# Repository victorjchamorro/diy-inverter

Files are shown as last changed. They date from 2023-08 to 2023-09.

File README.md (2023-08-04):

# diy-inverter
Creación de un inversor partiendo de un Xantrex ProWatt 1400i averiado

Serie de vídeos en youtube:
[youtube](https://www.youtube.com/playlist?list=PLBt3mBwJQwRWf2Qoqq8KDot9ghxqB0hle)

Imágenes:

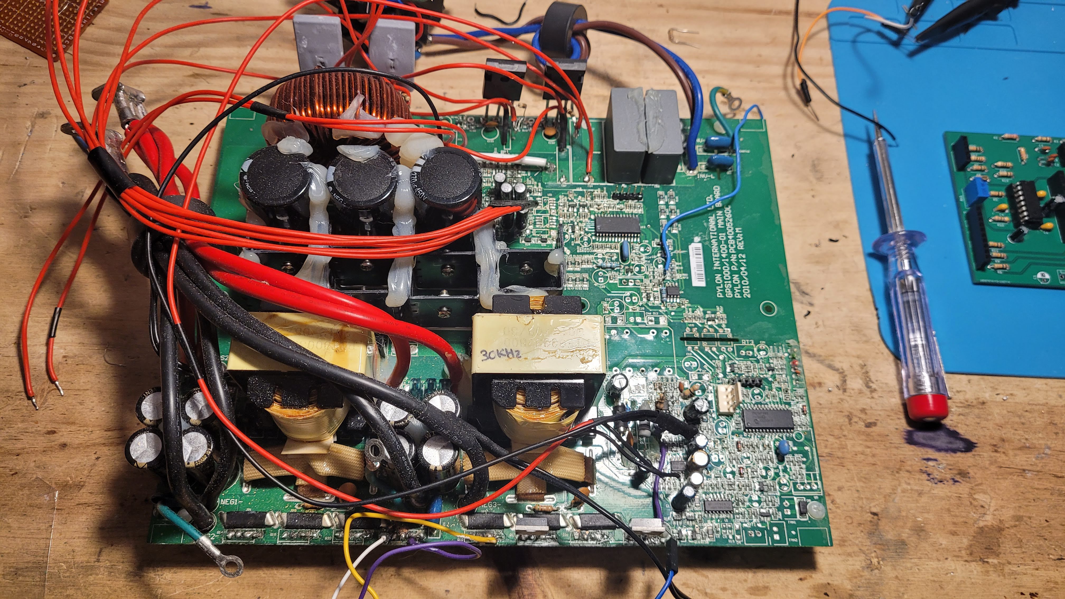
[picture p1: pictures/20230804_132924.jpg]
PCB Xantrex

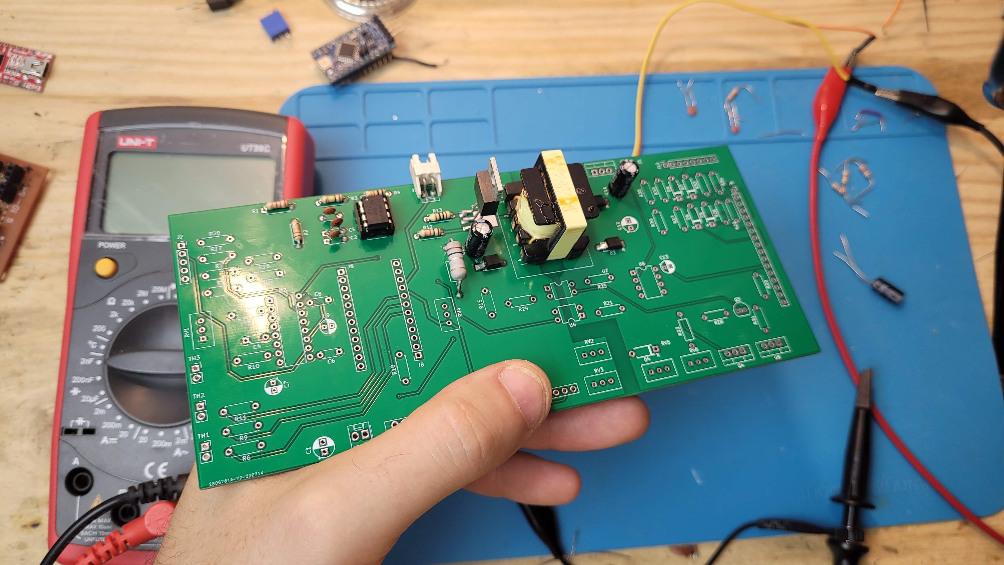
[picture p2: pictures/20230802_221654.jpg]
PCB DYI


La idea es remplazar toda la electrónica de control por un circuito nuevo, aprovechando los componentes de potencia existentes en la placa

- arduino: arduino code
- kicad: schemas and gerbers
- pictures: fotografías
- utl: utilidades

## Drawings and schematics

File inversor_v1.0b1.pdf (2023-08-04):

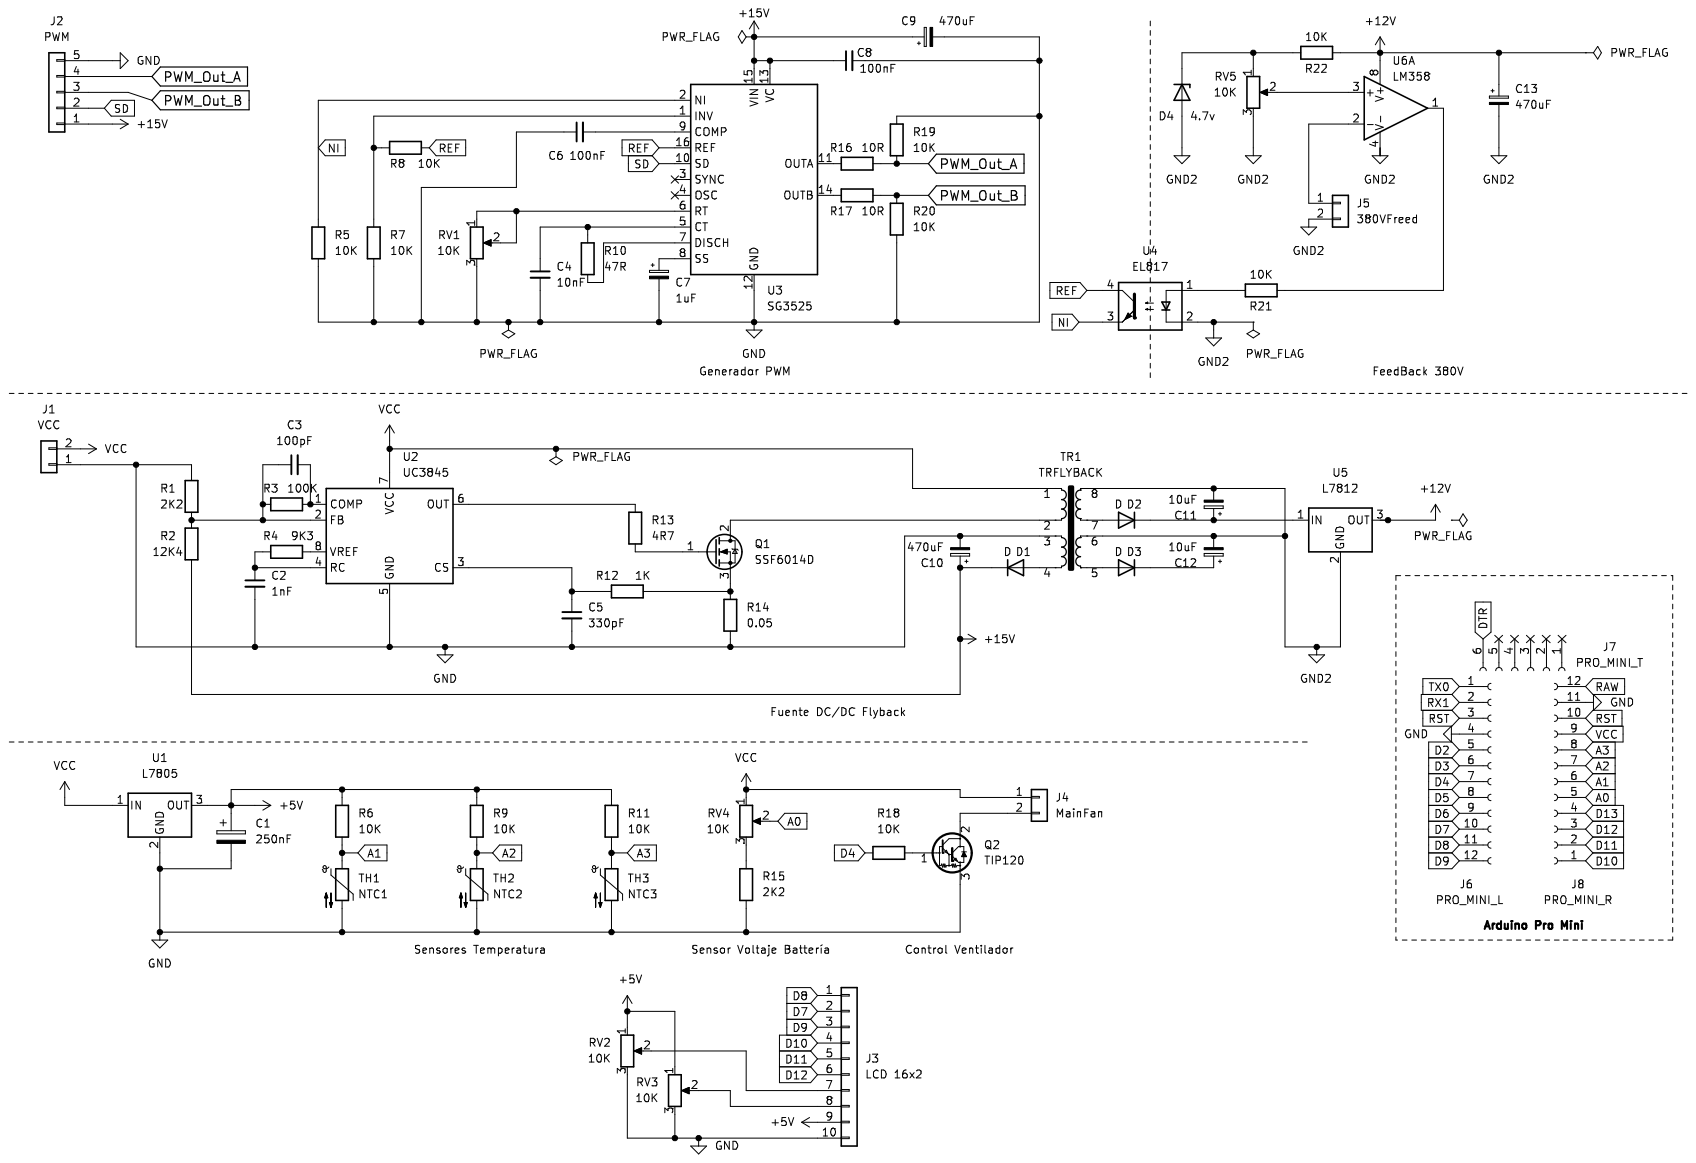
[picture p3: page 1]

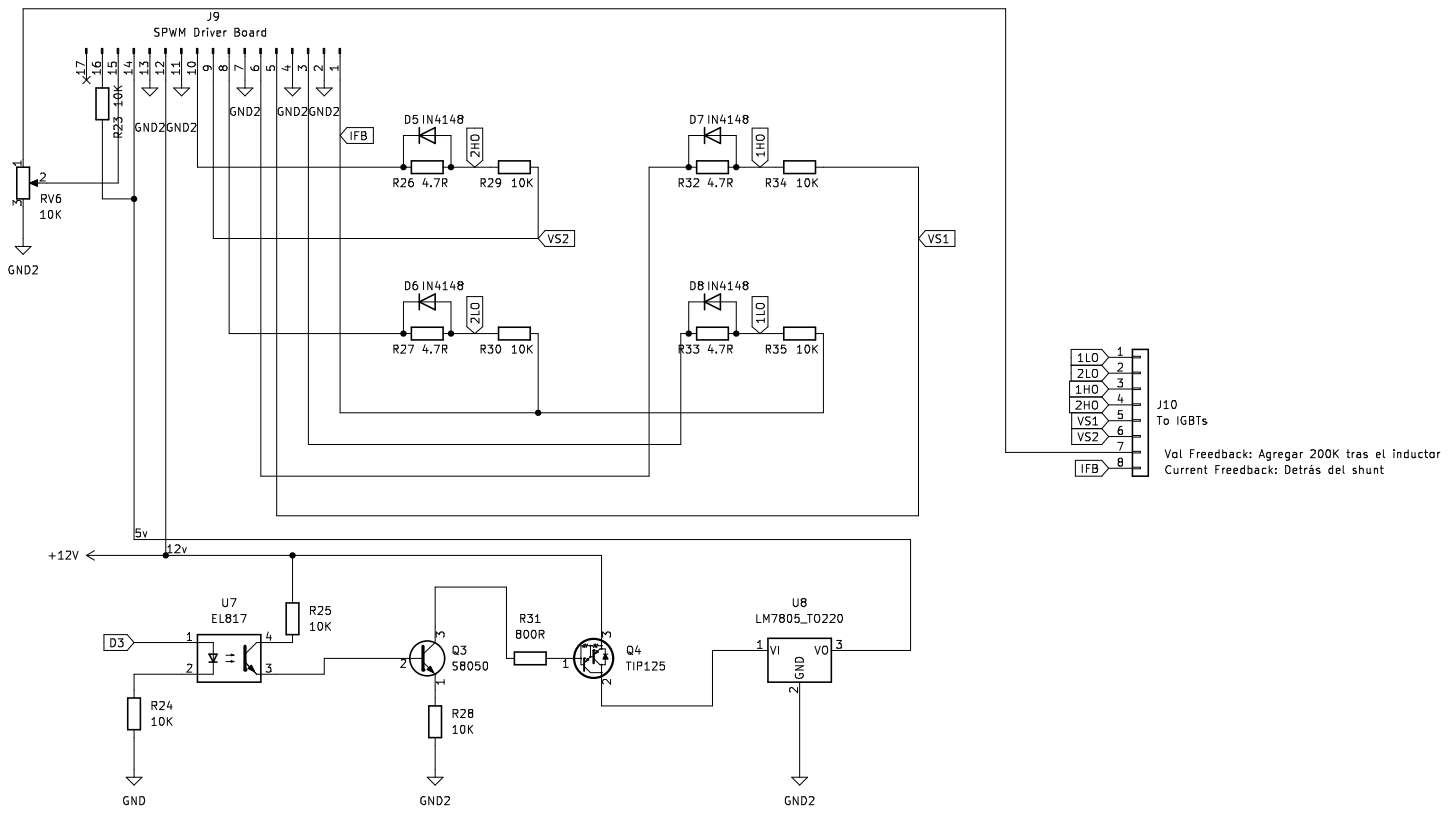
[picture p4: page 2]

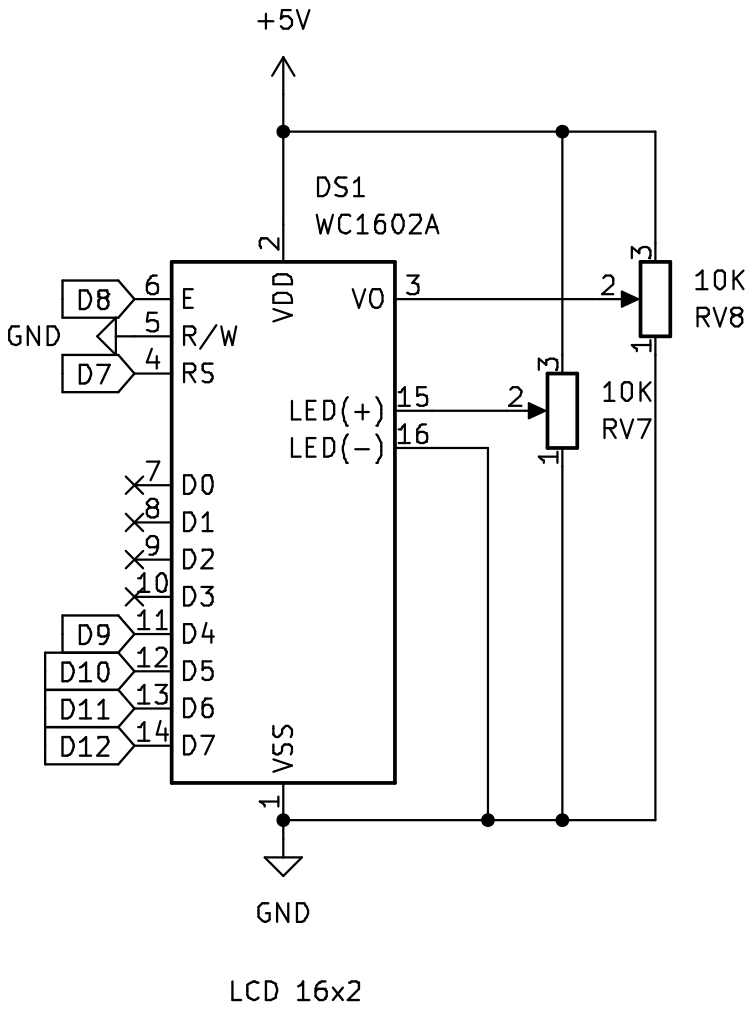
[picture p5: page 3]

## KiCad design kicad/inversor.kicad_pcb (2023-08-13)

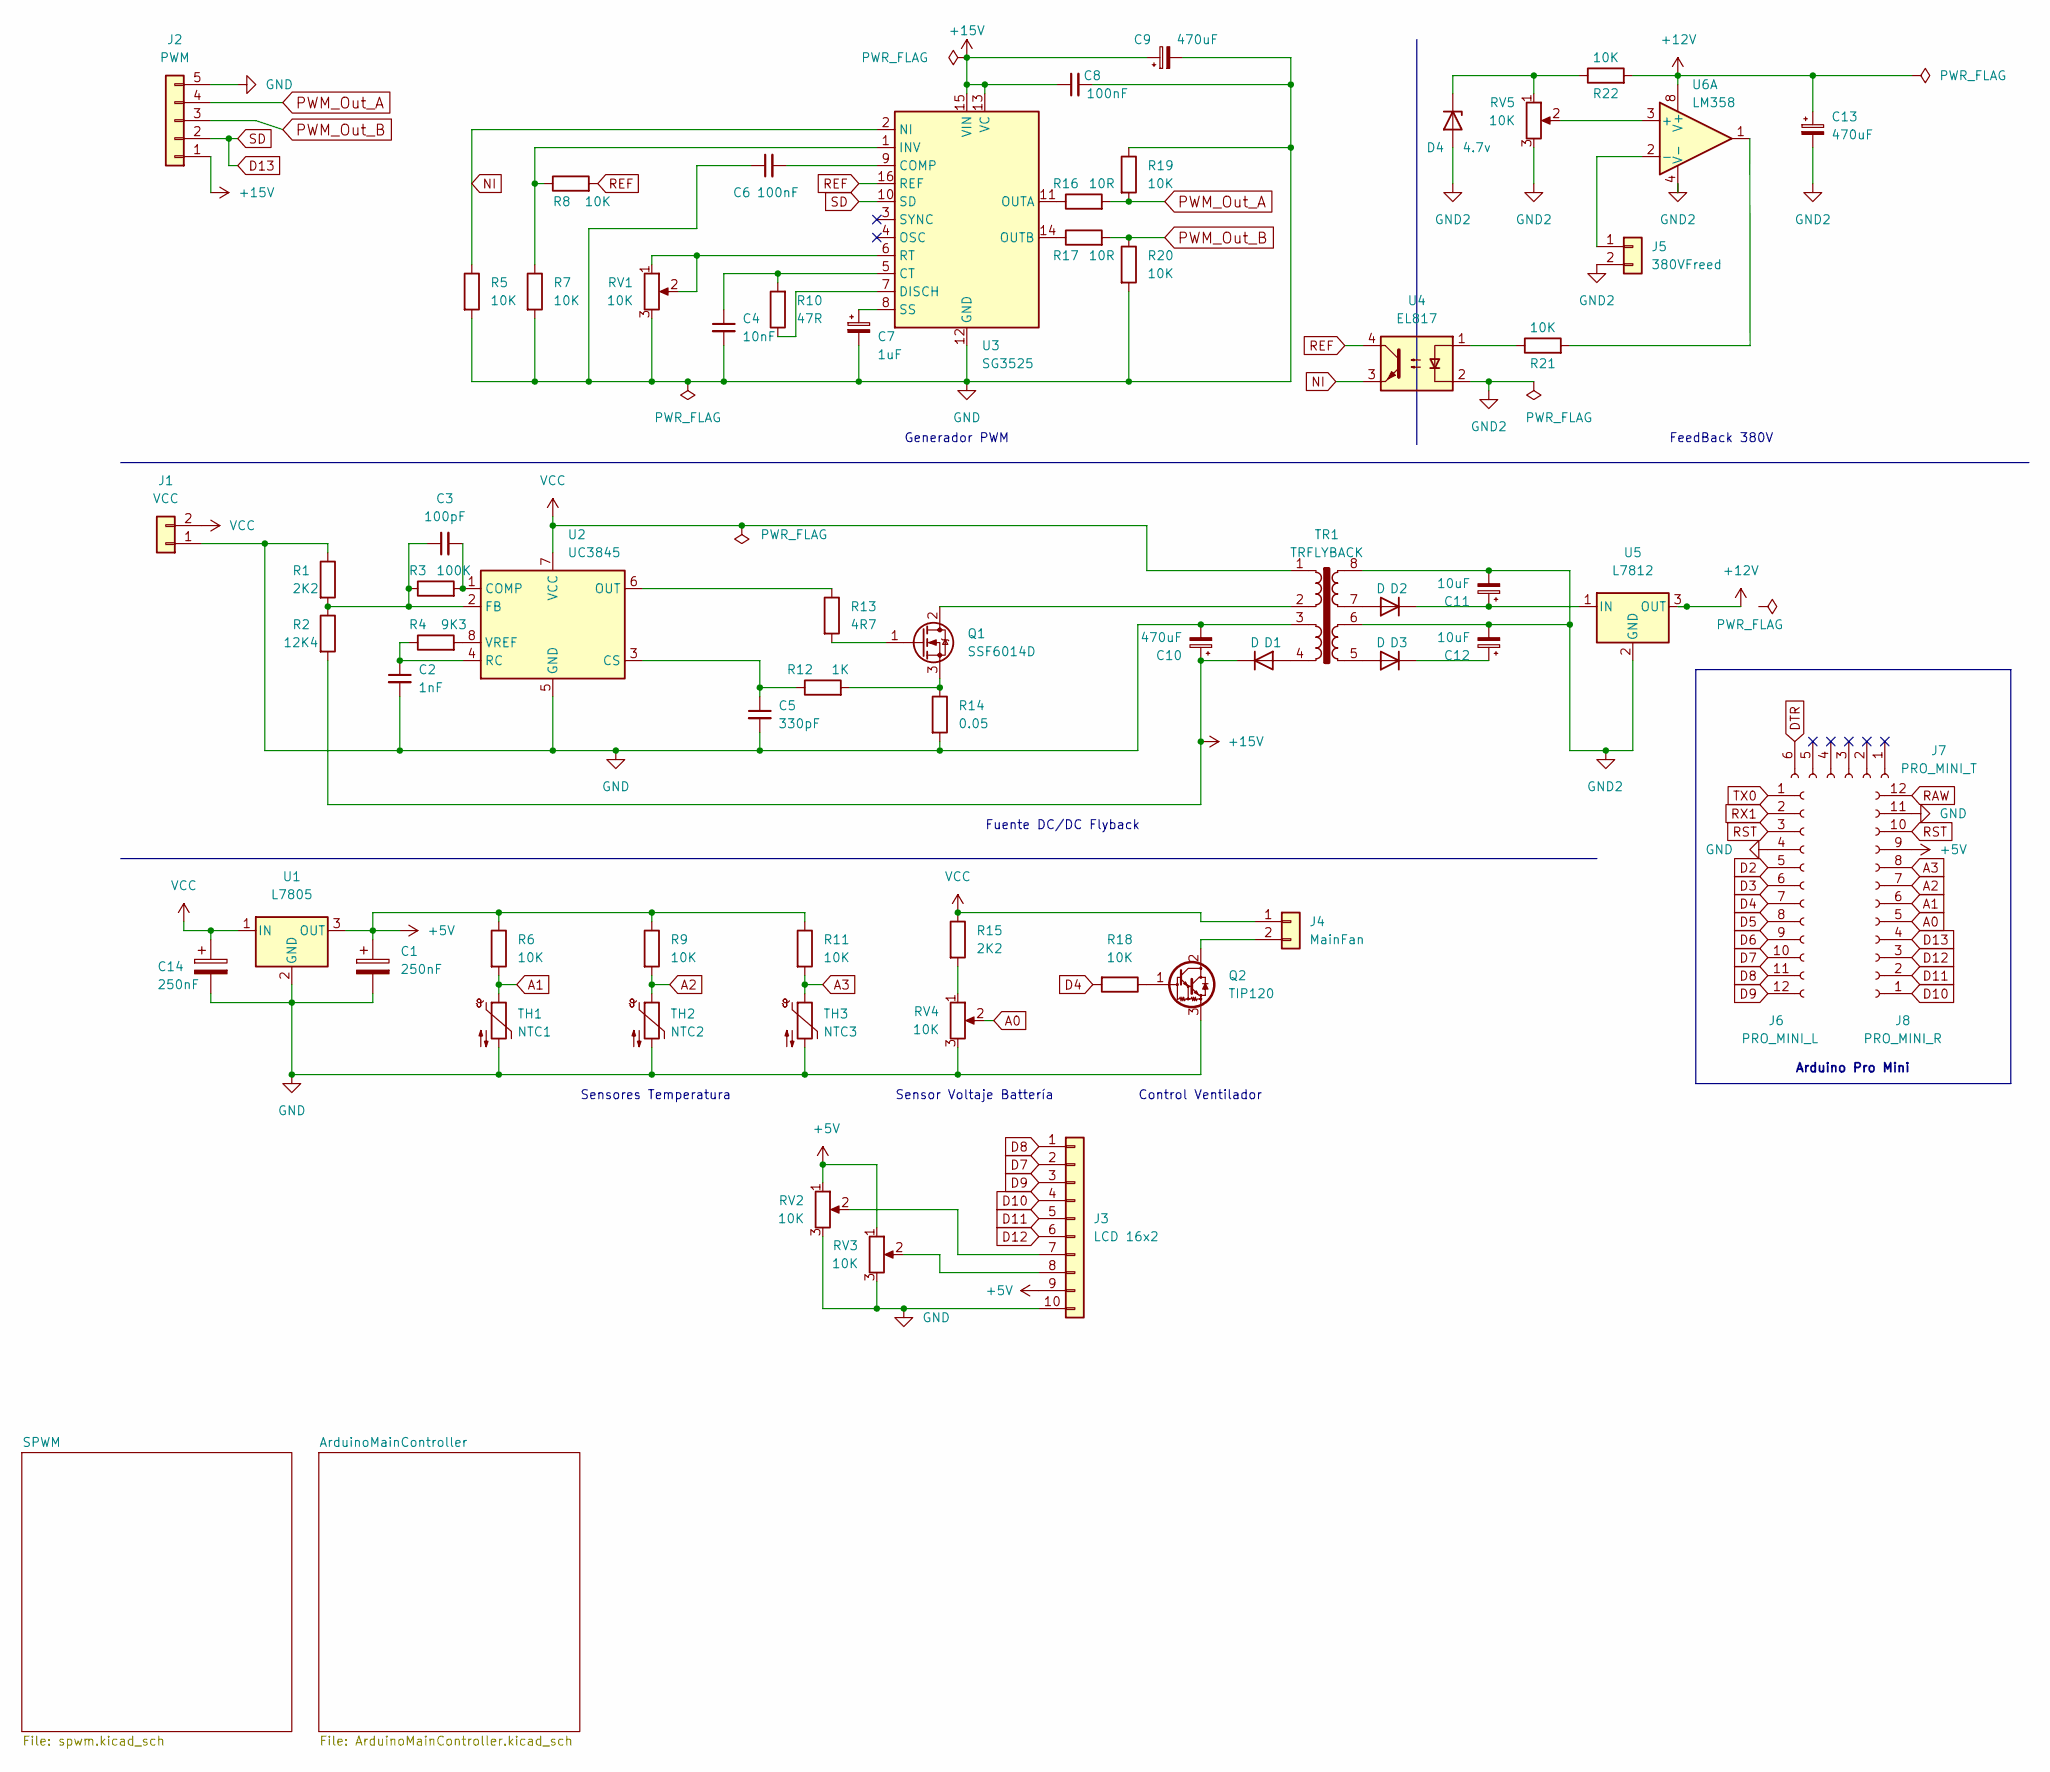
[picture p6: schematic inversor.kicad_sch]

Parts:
C1, C14: 250nF; CP_Radial_D5.0mm_P2.50mm
C2: 1nF; C_Disc_D4.3mm_W1.9mm_P5.00mm
C3: 100pF; C_Disc_D4.3mm_W1.9mm_P5.00mm
C4: 10nF; C_Disc_D4.3mm_W1.9mm_P5.00mm
C5: 330pF; C_Disc_D4.3mm_W1.9mm_P5.00mm
C6, C8: 100nF; C_Disc_D4.3mm_W1.9mm_P5.00mm
C7: 1uF; CP_Radial_D4.0mm_P2.00mm
C9, C10, C13: 470uF; CP_Radial_D4.0mm_P2.00mm
C11, C12: 10uF; CP_Radial_D5.0mm_P2.50mm
D1, D2, D3: D; D_A-405_P7.62mm_Horizontal
D4: 4.7v; D_A-405_P7.62mm_Horizontal
J1: VCC; Molex_KK-254_AE-6410-02A_1x02_P2.54mm_Vertical
J2: PWM; PinSocket_1x05_P2.54mm_Vertical
J3: LCD 16x2; PinSocket_1x10_P2.54mm_Vertical
J4: MainFan; Molex_KK-254_AE-6410-02A_1x02_P2.54mm_Vertical
J5: 380VFreed; PinSocket_1x02_P2.54mm_Vertical
J6: PRO_MINI_L; PinSocket_1x12_P2.54mm_Vertical
J7: PRO_MINI_T; PinSocket_1x06_P2.54mm_Vertical
J8: PRO_MINI_R; PinSocket_1x12_P2.54mm_Vertical
Q1: SSF6014D; TO-252-3_TabPin2
Q2: TIP120; TO-220-3_Vertical
R1, R15: 2K2; R_Axial_DIN0207_L6.3mm_D2.5mm_P7.62mm_Horizontal
R2: 12K4; R_Axial_DIN0207_L6.3mm_D2.5mm_P7.62mm_Horizontal
R3: 100K; R_Axial_DIN0207_L6.3mm_D2.5mm_P7.62mm_Horizontal
R4: 9K3; R_Axial_DIN0207_L6.3mm_D2.5mm_P7.62mm_Horizontal
R5, R6, R7, R8, R9, R11, R18, R19, R20, R21, R22: 10K; R_Axial_DIN0207_L6.3mm_D2.5mm_P7.62mm_Horizontal
R10: 47R; R_Axial_DIN0207_L6.3mm_D2.5mm_P7.62mm_Horizontal
R12: 1K; R_Axial_DIN0207_L6.3mm_D2.5mm_P7.62mm_Horizontal
R13: 4R7; R_Axial_DIN0207_L6.3mm_D2.5mm_P7.62mm_Horizontal
R14: 0.05; R_Axial_DIN0207_L6.3mm_D2.5mm_P15.24mm_Horizontal
R16, R17: 10R; R_Axial_DIN0207_L6.3mm_D2.5mm_P7.62mm_Horizontal
RV1, RV2, RV3, RV4, RV5: 10K; Potentiometer_Bourns_3296W_Vertical
TH1: NTC1; PinSocket_1x02_P2.54mm_Vertical
TH2: NTC2; PinSocket_1x02_P2.54mm_Vertical
TH3: NTC3; PinSocket_1x02_P2.54mm_Vertical
TR1: TRFLYBACK; Transformer_BlyBack_custom_01
U1: L7805; TO-220-3_Vertical
U2: UC3845; DIP-8_W7.62mm
U3: SG3525; DIP-16_W7.62mm
U4: EL817; DIP-4_W7.62mm
U5: L7812; TO-220-3_Vertical
U6: LM358; DIP-8_W7.62mm

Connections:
+5V: C1.1, J3.9, J8.9, R6.1, R9.1, R11.1, RV2.1, RV3.1, U1.3 (OUT)
+12V: C13.1, R22.2, U5.3 (OUT), U6.8 (V+); also elsewhere on the board
+15V: C8.1, C9.1, C10.1, D1.1 (K), J2.1, R2.2, U3.13 (VC), U3.15 (VIN)
A0: J8.5, RV4.2
A1: J8.6, R6.2, TH1.1
A2: J8.7, R9.2, TH2.1
A3: J8.8, R11.2, TH3.1
D2: J6.5
D3: J6.6; also elsewhere on the board
D4: J6.7, R18.2
D5: J6.8
D6: J6.9
D7: J3.2, J6.10
D8: J3.1, J6.11
D9: J3.3, J6.12
D10: J3.4, J8.1
D11: J3.5, J8.2
D12: J3.6, J8.3
D13: J2.2, J8.4, U3.10 (SD)
GND: C1.2, C2.2, C4.2, C5.2, C6.1, C7.2, C8.2, C9.2, C10.2, C14.2, J1.1, J2.5, J3.10, J6.4, J8.11, Q2.3 (E), R1.1, R5.2, R7.2, R14.2, R19.1, R20.2, RV1.3, RV2.3, RV3.3, RV4.3, TH1.2, TH2.2, TH3.2, TR1.3, U1.2 (GND), U2.5 (GND), U3.12 (GND); also elsewhere on the board
GND2: C11.2, C12.2, C13.2, D4.2 (A), J5.2, RV5.3, TR1.6, TR1.8, U4.2, U5.2 (GND), U6.4 (V-); also elsewhere on the board
NI: R5.1, U3.2 (NI), U4.3
unnamed: C2.1, R4.1, U2.4 (RC)
unnamed: C3.1, R1.2, R2.1, R3.1, U2.2 (FB)
unnamed: C3.2, R3.2, U2.1 (COMP)
unnamed: C4.1, R10.2, U3.5 (CT)
unnamed: C5.1, R12.1, U2.3 (CS)
unnamed: C6.2, U3.9 (COMP)
unnamed: C7.1, U3.8 (SS)
unnamed: C11.1, D2.1 (K), U5.1 (IN)
unnamed: C12.1, D3.1 (K)
unnamed: D1.2 (A), TR1.4
unnamed: D2.2 (A), TR1.7
unnamed: D3.2 (A), TR1.5
unnamed: D4.1 (K), R22.1, RV5.1
unnamed: J3.7, RV2.2
unnamed: J3.8, RV3.2
unnamed: J4.2, Q2.2 (C)
unnamed: J5.1, U6.2 (-)
unnamed: Q1.1 (G), R13.2
unnamed: Q1.2 (D), TR1.2
unnamed: Q1.3 (S), R12.2, R14.1
unnamed: Q2.1 (B), R18.1
unnamed: R4.2, U2.8 (VREF)
unnamed: R7.1, R8.1, U3.1 (INV)
unnamed: R10.1, U3.7 (DISCH)
unnamed: R13.1, U2.6 (OUT)
unnamed: R15.2, RV4.1
unnamed: R16.1, U3.11 (OUTA)
unnamed: R17.1, U3.14 (OUTB)
unnamed: R21.1, U4.1
unnamed: R21.2, U6.1
unnamed: RV1.1, RV1.2, U3.6 (RT)
unnamed: RV5.2, U6.3 (+)
PWM_Out_A: J2.4, R16.2, R19.2
PWM_Out_B: J2.3, R17.2, R20.1
RAW: J8.12
REF: R8.2, U3.16 (REF), U4.4
RST: J6.3, J8.10
RX1: J6.2
TX0: J6.1
VCC: C14.1, J1.2, J4.1, R15.1, TR1.1, U1.1 (IN), U2.7 (VCC)

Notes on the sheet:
FeedBack 380V
Sensores Temperatura
Generador PWM
Arduino Pro Mini
Control Ventilador
Sensor Voltaje Battería
Fuente DC/DC Flyback

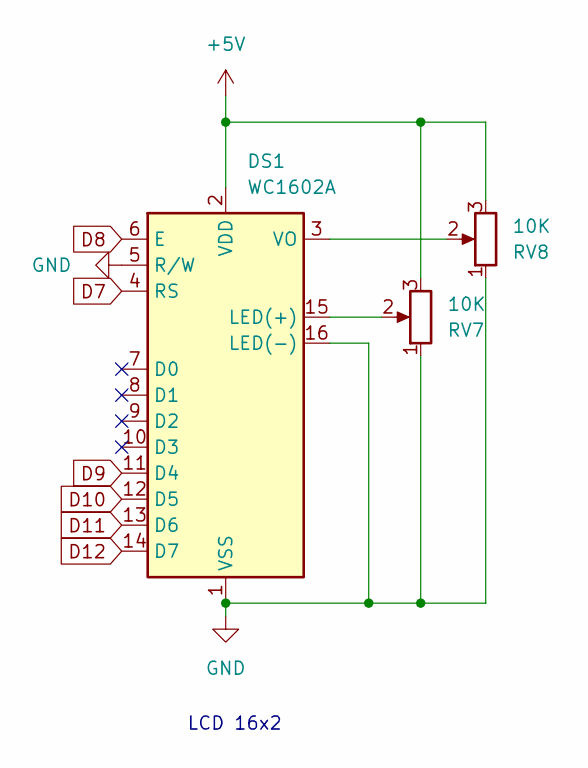
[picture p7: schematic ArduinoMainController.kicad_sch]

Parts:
DS1: WC1602A
RV7, RV8: 10K; Potentiometer_Bourns_3296W_Vertical

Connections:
unnamed: DS1.1 (VSS), DS1.5 (R/W), DS1.16 (LED(-)), RV7.1, RV8.1
unnamed: DS1.2 (VDD), RV7.3, RV8.3
unnamed: DS1.3 (VO), RV8.2
unnamed: DS1.15 (LED(+)), RV7.2

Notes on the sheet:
LCD 16x2

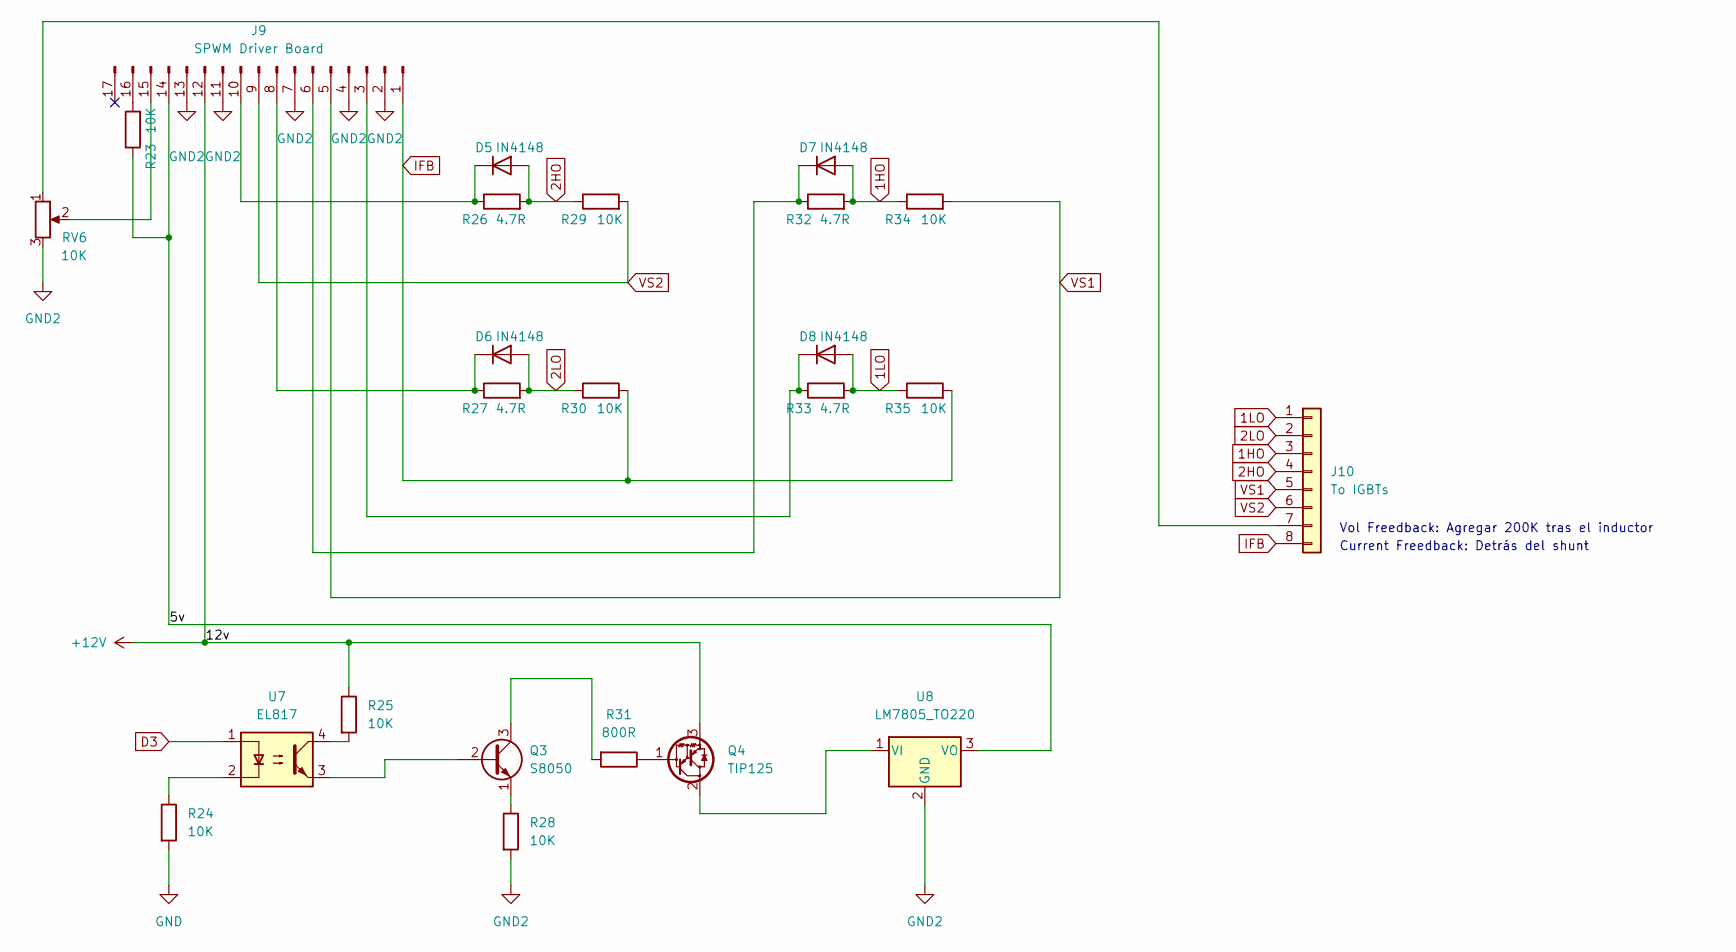
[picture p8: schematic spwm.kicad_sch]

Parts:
D5, D6, D7, D8: IN4148; D_A-405_P7.62mm_Horizontal
J9: SPWM Driver Board; PinSocket_1x17_P2.54mm_Vertical
J10: To IGBTs; PinSocket_1x08_P2.54mm_Vertical
Q3: S8050; TO-92_Inline
Q4: TIP125; TO-220-3_Vertical
R23, R24, R25, R28, R29, R30, R34, R35: 10K; R_Axial_DIN0207_L6.3mm_D2.5mm_P7.62mm_Horizontal
R26, R27, R32, R33: 4.7R; R_Axial_DIN0207_L6.3mm_D2.5mm_P7.62mm_Horizontal
R31: 800R; R_Axial_DIN0207_L6.3mm_D2.5mm_P7.62mm_Horizontal
RV6: 10K; Potentiometer_Bourns_3296W_Vertical
U7: EL817; DIP-4_W7.62mm
U8: LM7805_TO220; TO-220-3_Vertical

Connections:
1HO: D7.2 (A), J10.3, R32.2, R34.1
1LO: D8.2 (A), J10.1, R33.2, R35.1
2HO: D5.2 (A), J10.4, R26.2, R29.1
2LO: D6.2 (A), J10.2, R27.2, R30.1
+12V: J9.12, Q4.3 (E), R25.1; also elsewhere on the board
/SPWM/5v: J9.14, R23.1, U8.3 (VO)
D3: U7.1; also elsewhere on the board
GND: R24.2; also elsewhere on the board
GND2: J9.2, J9.4, J9.7, J9.11, J9.13, R28.2, RV6.3, U8.2 (GND); also elsewhere on the board
IFB: J9.1, J10.8, R30.2, R35.2
unnamed: D5.1 (K), J9.10, R26.1
unnamed: D6.1 (K), J9.8, R27.1
unnamed: D7.1 (K), J9.6, R32.1
unnamed: D8.1 (K), J9.3, R33.1
unnamed: J9.15, RV6.2
unnamed: J9.16, R23.2
unnamed: J10.7, RV6.1
unnamed: Q3.1 (E), R28.1
unnamed: Q3.2 (B), U7.3
unnamed: Q3.3 (C), R31.2
unnamed: Q4.1 (B), R31.1
unnamed: Q4.2 (C), U8.1 (VI)
unnamed: R24.1, U7.2
unnamed: R25.2, U7.4
VS1: J9.5, J10.5, R34.2
VS2: J9.9, J10.6, R29.2

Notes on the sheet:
Current Freedback: Detrás del shunt
Vol Freedback: Agregar 200K tras el inductor

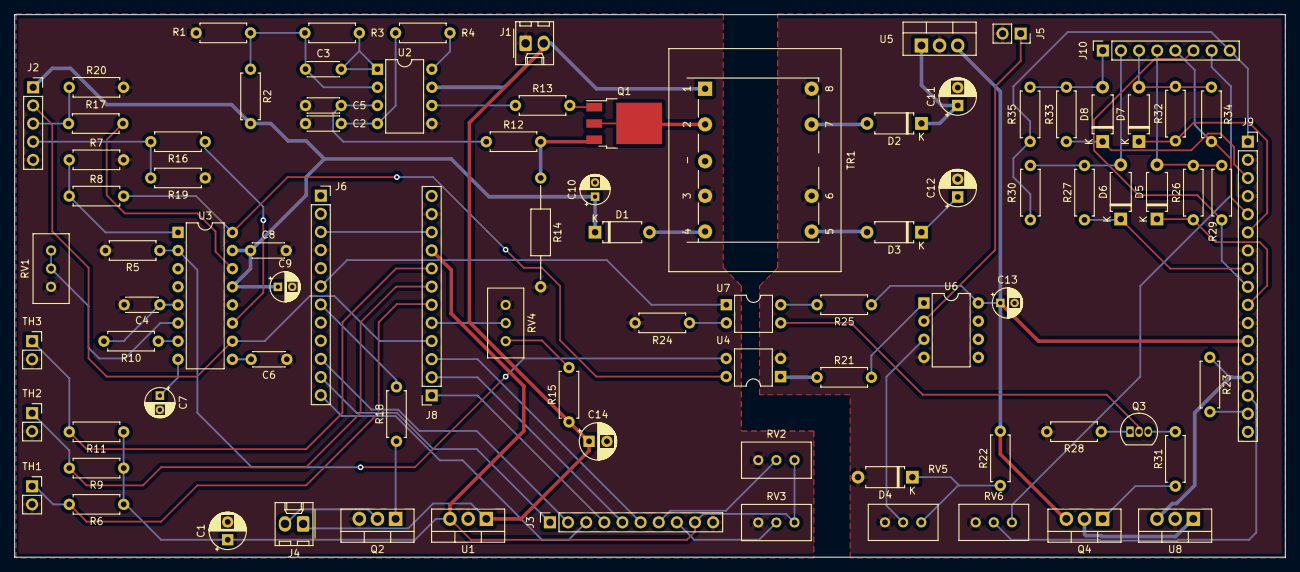
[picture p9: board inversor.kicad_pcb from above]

Board: 2 copper layers, 178.0 x 76.0 mm, 88 parts (0 on the bottom side), 78 nets.

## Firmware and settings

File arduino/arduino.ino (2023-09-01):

//Librerías
#include <LiquidCrystal.h>

// Pines
#define AVB A0  //Sensor Volt Batería
#define AT1 A1  //Sensor Temperatura 1
#define AT2 A2  //Sensor Temperatura 2
#define AT3 A3  //Sensor temperatura 3
#define DSD 13  //Salida digital de stop para el pwm de la 1ª etapa
#define DSPWM 3 //Salida digital de start para el generador spwm de la 2ª etapa
#define DFAN 5  //Salida digital para el ventilador

// Conf
#define MUESTRAS 100
#define DIVISOR1 3.7

// Debug
bool serial = false;

// Volt
int ADCvRef=0;
float voltBatt=0;
float atenuacion = 1.027;
float voltMax = 15.5;           //Voltaje Máximo
float voltMin = 10.5;           //Voltaje Mínimo
float voltMinRestart = 12.0;    //Voltaje recuperación tras voltaje mínimo
float voltMaxRestart = 14.0;    //Voltaje recuperación tras voltaje máximo

// Temp
float temp1 = 0;
float temp2 = 0;
float temp3 = 0;

float tempMax = 55.0;           //Temp Máxima
float tempMaxRestart = 40.0;    //Temp recuperación tras voltaje máximo
float tempStopFan = 34.0;       //Temp apagado ventilador
float tempStartFan = 40.0;      //Temp encendido ventilador


// Tiempos y control
unsigned long tError = 0;   //milisegundo en el cuall ocurrió el error de voltaje
int tErrorDuration = 4000;  //milisegundos mínimos que durará el estado de error (para evitar rebotes)
bool error = false;         //Estado pwm parado por error
bool fanOn = false;         //Estado de encendido del ventilador

int pasoTemp = 1;

int estadoIcono = 0;

// Manejo de la pantalla LCD
LiquidCrystal lcd(7, 8, 9, 10, 11 , 12);

//Setup
void setup() {
  
  if (serial) Serial.begin(9600);

  pinMode(DFAN, OUTPUT);
  pinMode(DSD,  OUTPUT);
  pinMode(DSPWM,OUTPUT);

  initLCD();

  delay(1500);               //Esperamos para que el voltaje del bus de alta esté casi en nominal (380DC)
  
  statusRun();
  
}

// Resetea el error y limpia los tiempos de error
void resetError(){
  tError=0;
  statusRun();
}

// Para las dos etapas y marca el estado del inversor como error
void statusError(){
  error = true;
  digitalWrite(DSD,HIGH);
  digitalWrite(DSPWM,LOW);
}

// Arranca las 2 etapas y quita el estado de error
void statusRun(){
  error = false;
  
  //Arrancamos la 1ª etapa para que cuando arranque el generador spwm de la 2ª etapa el bus de alta ya esté cercano a los 380v DC
  digitalWrite(DSD,LOW);    //Arrancamos el generador PWM de la primera etapa
  delay(500);               //Esperamos para que el voltaje del bus de alta esté casi en nominal (380DC)
  digitalWrite(DSPWM,HIGH); //Arrancamos el generador SPWM de la segunda etapa
}

// Inicializa la pantalla LCD y pinta los textos que no cambian
void initLCD(){
  
  lcd.begin(16, 2);

  /*byte customChar1[] = {
        B00111,
        B01111,
        B11111,
        B11111,
        B11001,
        B11001,
        B11110,
        B11110
      };
  
    byte customChar2[] = {
        B11100,
        B11110,
        B11111,
        B11111,
        B10011,
        B10011,
        B01111,
        B01111
      };
      
    byte customChar3[] = {
        B11111,
        B01111,
        B00101,
        B00010,
        B00111,
        B00111,
        B00000,
        B00000
      };
      
    byte customChar4[] = {
        B11111,
        B11110,
        B10100,
        B01000,
        B11100,
        B11100,
        B00000,
        B00000
      };

      lcd.createChar(0, customChar1);
      lcd.createChar(1, customChar2);
      lcd.createChar(2, customChar3);
      lcd.createChar(3, customChar4);

    byte customChar5[] = {
          B11000,
          B10000,
          B00000,
          B00000,
          B00110,
          B00110,
          B00001,
          B00001
        };
    
      byte customChar6[] = {
          B00011,
          B00001,
          B00000,
          B00000,
          B01100,
          B01100,
          B10000,
          B10000
        };
        
      byte customChar7[] = {
          B00000,
          B10000,
          B11010,
          B11101,
          B11000,
          B11000,
          B11111,
          B11111
        };
        
      byte customChar8[] = {
          B00000,
          B00001,
          B01011,
          B10111,
          B00011,
          B00011,
          B11111,
          B11111
        };

        lcd.createChar(4, customChar5);
        lcd.createChar(5, customChar6);
        lcd.createChar(6, customChar7);
        lcd.createChar(7, customChar8);
    
  
  /*  // Test Caracteres
      // LCD
      for(int i=0; i<=255; i++){
        lcd.clear();
        lcd.setCursor(0,0);
        lcd.print(i);
        lcd.setCursor(5,0);
        lcd.print(i, BIN);
        lcd.setCursor(0,1);
        byte z = (int) i;;
        lcd.write(z);
        delay(500);
      }
  */
  
  lcd.clear();
  lcd.setCursor(0,0);
  lcd.write("Batt: ");
  lcd.setCursor(0,1);
  lcd.write("Temp  :");
}

// Actualiza la pantalla LCD
void printInfo(){
  if (serial){
    if (error){
      Serial.println("ERROR: Voltaje o temperatura fuera de rango");
    }
    //Serial.print("vRefADC: ");
    //Serial.println(ADCvRef/1000.0/atenuacion);
    Serial.print("vBat: ");
    Serial.println(voltBatt);
    Serial.print("Temp  :");
    Serial.println(temp1);
  }

  if (pasoTemp == 1){
    initLCD();
  }
  
  

  lcd.setCursor(10,0);
  lcd.print(round(voltBatt*100)/100.0,DEC);
  lcd.setCursor(15,0);
  lcd.write("V");

  //Temp 1;

  switch(pasoTemp){
    case 1:
      pasoTemp = 2;
      lcd.setCursor(5,1);
      lcd.print("1");
      lcd.setCursor(10,1);
      lcd.print(round(temp1*100)/100.0,DEC);
      lcd.setCursor(15,1);
      lcd.write(223); //Carácter º (Grados)
      break;
    case 2:
      pasoTemp = 3;
      lcd.setCursor(5,1);
      lcd.print("2");
      lcd.setCursor(10,1);
      lcd.print(round(temp2*100)/100.0,DEC);
      lcd.setCursor(15,1);
      lcd.write(223); //Carácter º (Grados)
      break;
    case 3:
      pasoTemp = 1;
      lcd.setCursor(5,1);
      lcd.print("3");
      lcd.setCursor(10,1);
      lcd.print(round(temp3*100)/100.0,DEC);
      lcd.setCursor(15,1);
      lcd.write(223); //Carácter º (Grados)
      break;
  }

  if (error){
    if (estadoIcono<1){

        estadoIcono=estadoIcono+1;
  
        lcd.setCursor(7,0);
        lcd.print("FA");
        lcd.setCursor(7,1);
        lcd.print("IL");
        /*lcd.write(byte(0));
        lcd.setCursor(8,0);
        lcd.write(byte(1));
        lcd.setCursor(7,1);
        lcd.write(byte(2));
        lcd.setCursor(8,1);
        lcd.write(byte(3));
          */
          
    }else{
  
      estadoIcono=estadoIcono+1;
      if (estadoIcono>1){
        estadoIcono=0;
      }
      lcd.setCursor(7,0);
      lcd.print("IL");
      lcd.setCursor(7,1);
      lcd.print("FA");
      /*
      lcd.setCursor(7,0);
      lcd.write(byte(4));
      lcd.setCursor(8,0);
      lcd.write(byte(5));
      lcd.setCursor(7,1);
      lcd.write(byte(6));
      lcd.setCursor(8,1);
      lcd.write(byte(7));
      */
    }

/*
    
    lcd.setCursor(7,0);
    lcd.write(byte(0));
    lcd.setCursor(8,0);
    lcd.write(byte(1));
    lcd.setCursor(7,1);
    lcd.write(byte(2));
    lcd.setCursor(8,1);
    lcd.write(byte(3));
    */
  }else{
    lcd.setCursor(7,0);
    lcd.write(" ");
    lcd.setCursor(8,0);
    lcd.write(" ");
    lcd.setCursor(7,1);
    lcd.write(" ");
    lcd.setCursor(8,1);
    lcd.write(" ");
  }
}

// Devuelve true si el voltaje de batería es bajo
bool checkVoltMin(){
  bool minerror = (voltBatt<voltMin);
  if (minerror){
    tError = millis();
  }
  return minerror;
}

// Devuelve true si el voltaje de batería es elevado
bool checkVoltMax(){
  bool maxerror = (voltBatt>voltMax);
  if (maxerror){
    tError = millis();
  }
  return maxerror;
}

// Devuelve true si la temperatura es elevada
bool checkTempMax(){
  bool maxerror = (temp1>tempMax) || (temp2>tempMax) || (temp3>tempMax);
  if (maxerror){
    tError = millis();
  }
  return maxerror;
}

//Control del Ventilador
bool checkVentilador(){
  if (fanOn == true){
    //Miro si tengo que apagar
    if(temp1<tempStopFan && temp2<tempStopFan && temp3<tempStopFan){
      //digitalWrite(DFAN,LOW);
      analogWrite(DFAN,0);
      fanOn = false;
    }
  }else{
    //Miro si tengo que encender
    if(temp1>tempStartFan || temp2>tempStartFan || temp3>tempStartFan){
      analogWrite(DFAN,170); //Usamos pwm para ajustar a 12v en lugar de los 16 que tenemos
      fanOn = true;
    }
  }
  
}


/**
 * Voltaje de Bateria en voltios
 */
float vBatt(){
  double volts = 0;
  
  for(int i=0;i < MUESTRAS; i++){    
    volts = volts + ((analogRead(AVB) / 1023.0) * ADCvRef);
    delay(1);
  }
  return (((volts / MUESTRAS) / 1000) / atenuacion)*DIVISOR1;
}


/**
 * Temperatura de la sonda en el pin indicado en ºC
 */
float cTemp(int pin){
  //Medimos voltaje del divisor de tensión
  double volts = 0;
  
  for(int i=0;i < MUESTRAS; i++){    
    volts = volts + ((analogRead(pin) / 1023.0) * ADCvRef);
    delay(1);
  }
  double V = (((volts / MUESTRAS) / 1000.0) / atenuacion)*1.0;

  //Curva logarítmica obtenida con la hoja de cálculo
  return -34.4456*log(V) + 56.68735;
}

/**
 * Devuelve el voltaje de referencia ~5v ó ~3.3v en milivoltios
 */
int vRefADC(){
   long result;
   ADMUX = _BV(REFS0) | _BV(MUX3) | _BV(MUX2) | _BV(MUX1);
   delay(2);
   ADCSRA |= _BV(ADSC);
   while (bit_is_set(ADCSRA,ADSC));
   result = ADCL;
   result |= ADCH<<8;
   result = 1125300L / result;
   return result;
}

void loop() {
  // put your main code here, to run repeatedly:

  ADCvRef = vRefADC();
  voltBatt= vBatt();
  temp1   = cTemp(AT1);
  temp2   = cTemp(AT2);
  temp3   = cTemp(AT3);

  checkVentilador();

  if (error == true){
    unsigned long now = millis();

    if ((tError + tErrorDuration) < now){
      //Ha pasado el tiempo de error, chequeamos si ya estamos en rangos de recuperación
      if(voltBatt>voltMinRestart &&  voltBatt < voltMaxRestart && temp1<tempMaxRestart && temp2<tempMaxRestart && temp3<tempMaxRestart){   
        resetError();
      }else{
        //Volvemos a resetear el tiempo de error para que vuelva a esperar
        tError=now;
      }
    }
    
  }
  
  if (error==false){
    //Si no estamos en error, revisamos los parámetros
    
    //Voltajes:
    if (error == false && (checkVoltMin() || checkVoltMax())){
      statusError();
    }

    //Temperatura:
    if (error == false && checkTempMax()){
      statusError();
    }
  
  }

  printInfo();
  delay(500);
}

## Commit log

2023-08-04 Versión 1.0 mandada a fabricar prototipo
    [ArduinoMainController.kicad_sch, arduino_pwm.kicad_sch, curva_sensor_temperatura.ods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]
2023-08-04 FIX: VCC Arduino 5v en lugar de VCC FIX: Divisor de tension para sensor de voltaje de batería con resistencia en la parte de vcc en lugar de gnd
    [inversor.kicad_pcb, inversor.kicad_sch]
2023-08-13 Fix: - Agregado condensador en la linea VCC - Agregada línea entre D13 del arduino y DS del SG3525 para poder detenerlo - Ajustes en pistas
    [inversor.kicad_pcb, inversor.kicad_sch]
2023-08-29 Agregadas la mediciones de los 3 sensores de temperatura al LCD y a los chequeos
2023-08-30 Ajustes firmware arduino: mejoras ruido LCD y calibraciones
2023-09-01 Ajustes en temperaturas para el manejo del ventilador
